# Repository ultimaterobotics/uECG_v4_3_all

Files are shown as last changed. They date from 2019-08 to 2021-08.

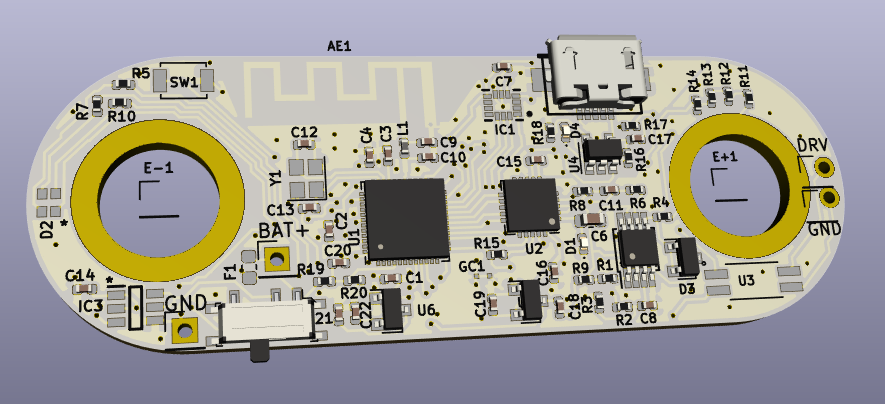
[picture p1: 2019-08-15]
pcb/uECG_rev4_render.png

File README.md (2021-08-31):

# uECG
uECG - very small wearable ECG device that sends raw and processed data over BLE

**This is an old repository - new version is located here: https://github.com/ultimaterobotics/uECG (and is divided into multiple repositories for relevant parts of the project, links are in description)**

Project is in active development stage, at the current moment we have shared:
 * schematics and PCB design
 * ECG monitor program based on Node.js, cross-platform
 * ECG monitor program for Linux (outdated: might not work properly, please use cross-platform version instead)
 * Firmware for the main unit, rather stable and reliable build. Next planned major update will cover better beat detection and more robust bpm processing. 
 * Firmware for the base unit that supports uploading uECG firmware via radio
 * Android app with major rework, quite stable now
 * bootloader code for USB base station: supports base firmware update via USB without the need of STLink programmer
 * bootloader code for uECG device: supports firmware update via radio (requires base with new firmware, old base firmware doesn't support this function)

You can follow the project on Hackaday: https://hackaday.io/project/164486-uecg-a-very-small-wearable-ecg

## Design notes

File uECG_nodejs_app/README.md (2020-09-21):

## uECG PC monitor - browser version, based on node.js

This app at the moment basically duplicates functionality of Android app, but works with x8 higher data rate. In the near future we plan to add support of multiple devices and reduce amount of lost data, then focus on data analysis

## Usage

1. Install Node JS (with npm). The process is quite intuitive and there are plenty of tutorials on how to make it
2. Download the app (git clone, or simply download all files from this folder in a convenient place)
3. Go to the app folder via command line. For this:
  - on Linux and macOS: start the terminal, run series of `cd <folder_name>` commands to get to the folder with downloaded app (where "server.js" file is located)
 - on Windows: start cmd app for accessing command line, if the app folder is not on disk C - run `D:` if it's on D, `E:` if it's on E etc, then run series of `cd <folder_name>` commands to get to the folder with downloaded app (where "server.js" file is located)
4. Install two required packages by running commands:
```
npm install express
npm install serialport
```
5. On Windows and macOS, install drivers for cp2102 chips from here: https://www.silabs.com/products/development-tools/software/usb-to-uart-bridge-vcp-drivers (not needed on Linux)
6. Start the server via command line interface: while in the app folder, run `node server.js`
7. In browser, enter address 127.0.0.1:8080 to access the UI. Note: if you already have some web development environment running on the port 8080, node server won't override it - in this case you can change the port number in the last line of server.js to any other value (and use it in browser correspondingly)
8. On uECG device, after it's turned on and finished blinking startup sequence, press button once to switch it into direct stream mode - after that, you should immediately see data in the browser interface. (pressing the button 2nd time would switch it in arduino-compatible streaming mode, also recognized by the base station, and pressing it for the 3rd time returns to BLE mode, the base won't receive this signal)

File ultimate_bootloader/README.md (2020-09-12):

Base unit bootloader. Supports uploading code via USB - so once it's uploaded via STLink, further updates can be performed more easily. Runs code located at address 0x4000 - so requires firmware to be built with  FLASH (rx) : ORIGIN = 0x04000 in .ld file.

Bootloader waits for firmware update request for 2.5 seconds, then starts the code. Can't auto-reset the base on request (like Arduino) due to missing connection on the base station PCB - base was designed long before bootloader appeared in our plans :)

# bootloader notes

Creating a bootloader for nRF52x chips was our goal for a long while, yet for a long time it didn't work. Somehow we couldn't find any clear instructions how to make it - and it has 3 points of failure, so it's really complicated to make it by trial-and-error.
Eventually it did work though, so I will outline those points:

1. jump to the right address. Jump code must be handled by assembly, and jump itself is a simple BX command, a 5-lines ASM function can conveniently wrap all that's needed in this regard (in our implementation you can find it under the name start_code2(uint32_t start_addr)). But! If you assume that if program starts at 0x4000 then jump should be performed to 0x4000 - you are wrong! After compiling binary code, program's start point is storen in 2nd 32-bit word from the start. So bytes 4-7 of the .bin file define address where jump should be performed.

2. before making the jump, all interrupts must be disabled and VTOR register updated - without this, interrupts won't work. Our current level of understanding isn't good enough to properly explain details, basically VTOR tells where to look for interrup handling functions, and by default it points at bootloader's interrupts. After this interrupts should be enabled again (but not called) - so the program that would be launched has access to them. This piece is handled in our code by function binary_exec(uint32_t address)

3. target app must be compiled with proper origin address. First bytes of the flash memory are occupied by bootloader, so target app should start at higher address - and all function calls should know that it's not starting at zero. To do this, in .ld file an offset must be specified:   FLASH (rx) : ORIGIN = 0x04000 (if bootloader writes program code starting at 0x4000 and uses bytes 0x4004-0x4007 to determine jump point for starting the program.

Keeping these 3 points in mind you should be able to write your own bootloader without any trouble :)

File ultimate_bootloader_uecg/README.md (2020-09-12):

uECG device bootloader code with radio uploading capability.

Bootloader waits for 1.5 seconds after powering on uECG - if button is pressed within this time, it enters wireless update mode for 15 seconds (if code update wasn't started in this time frame, update is cancelled and unit proceeds to normal boot).

Wireless update requires base station with this capability (old base firmware doesn't support it). Update is safe in the sense that it can't overwrite the bootloader: if for any reason attemp wasn't successful, it can be repeated as many times as needed.

Bootloader runs code located at address 0x4000 so firmware should be built with FLASH (rx) : ORIGIN = 0x04000 in .ld file (bootloader ignores attempts to write at addresses below 0x4000).

## bootloader notes

General part (a copy of notes from USB bootloader):

Creating a bootloader for nRF52x chips was our goal for a long while, yet for a long time it didn't work. Somehow we couldn't find any clear instructions how to make it - and it has 3 points of failure, so it's really complicated to make it by trial-and-error. Eventually it did work though, so I will outline those points:

jump to the right address. Jump code must be handled by assembly, and jump itself is a simple BX command, a 5-lines ASM function can conveniently wrap all that's needed in this regard (in our implementation you can find it under the name start_code2(uint32_t start_addr)). But! If you assume that if program starts at 0x4000 then jump should be performed to 0x4000 - you are wrong! After compiling binary code, program's start point is storen in 2nd 32-bit word from the start. So bytes 4-7 of the .bin file define address where jump should be performed.

before making the jump, all interrupts must be disabled and VTOR register updated - without this, interrupts won't work. Our current level of understanding isn't good enough to properly explain details, basically VTOR tells where to look for interrup handling functions, and by default it points at bootloader's interrupts. After this interrupts should be enabled again (but not called) - so the program that would be launched has access to them. This piece is handled in our code by function binary_exec(uint32_t address)

target app must be compiled with proper origin address. First bytes of the flash memory are occupied by bootloader, so target app should start at higher address - and all function calls should know that it's not starting at zero. To do this, in .ld file an offset must be specified: FLASH (rx) : ORIGIN = 0x04000 (if bootloader writes program code starting at 0x4000 and uses bytes 0x4004-0x4007 to determine jump point for starting the program.

Keeping these 3 points in mind you should be able to write your own bootloader without any trouble :)

### Radio specific part:

Radio packets arrive corrupted or completely missing way too often to write them directly on flash. In our implementation each packet has 3 checksums (total, odd, every 3rd byte) and sends confirmation after every packet (if base didn't receive confirmation, it re-sends packet, so we also need to handle duplicate packets). But when all of it is done properly, the process seems to be quite reliable - it passed all tests with moving unit out of range, keeping it at max range (so less than half packets can get through), cutting power in the middle - so it looks ok for now, even though a bit slow (unnecessarily slow, but rewriting it requires time we need to move other parts of the project - will do that later, as always :) )

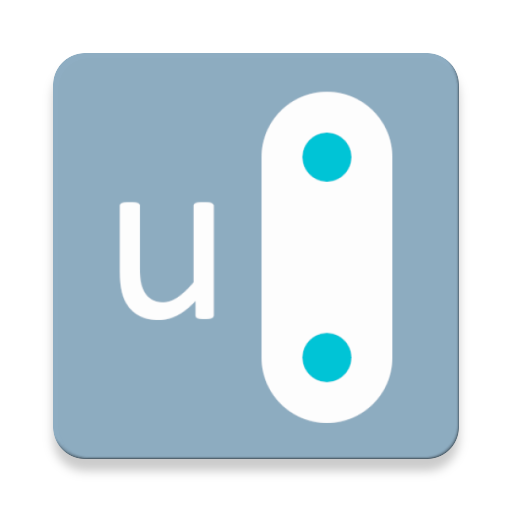
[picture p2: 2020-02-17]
uECG_v4_2_monitor/uECG_v4_2/src/main/ic_launcher-web.png

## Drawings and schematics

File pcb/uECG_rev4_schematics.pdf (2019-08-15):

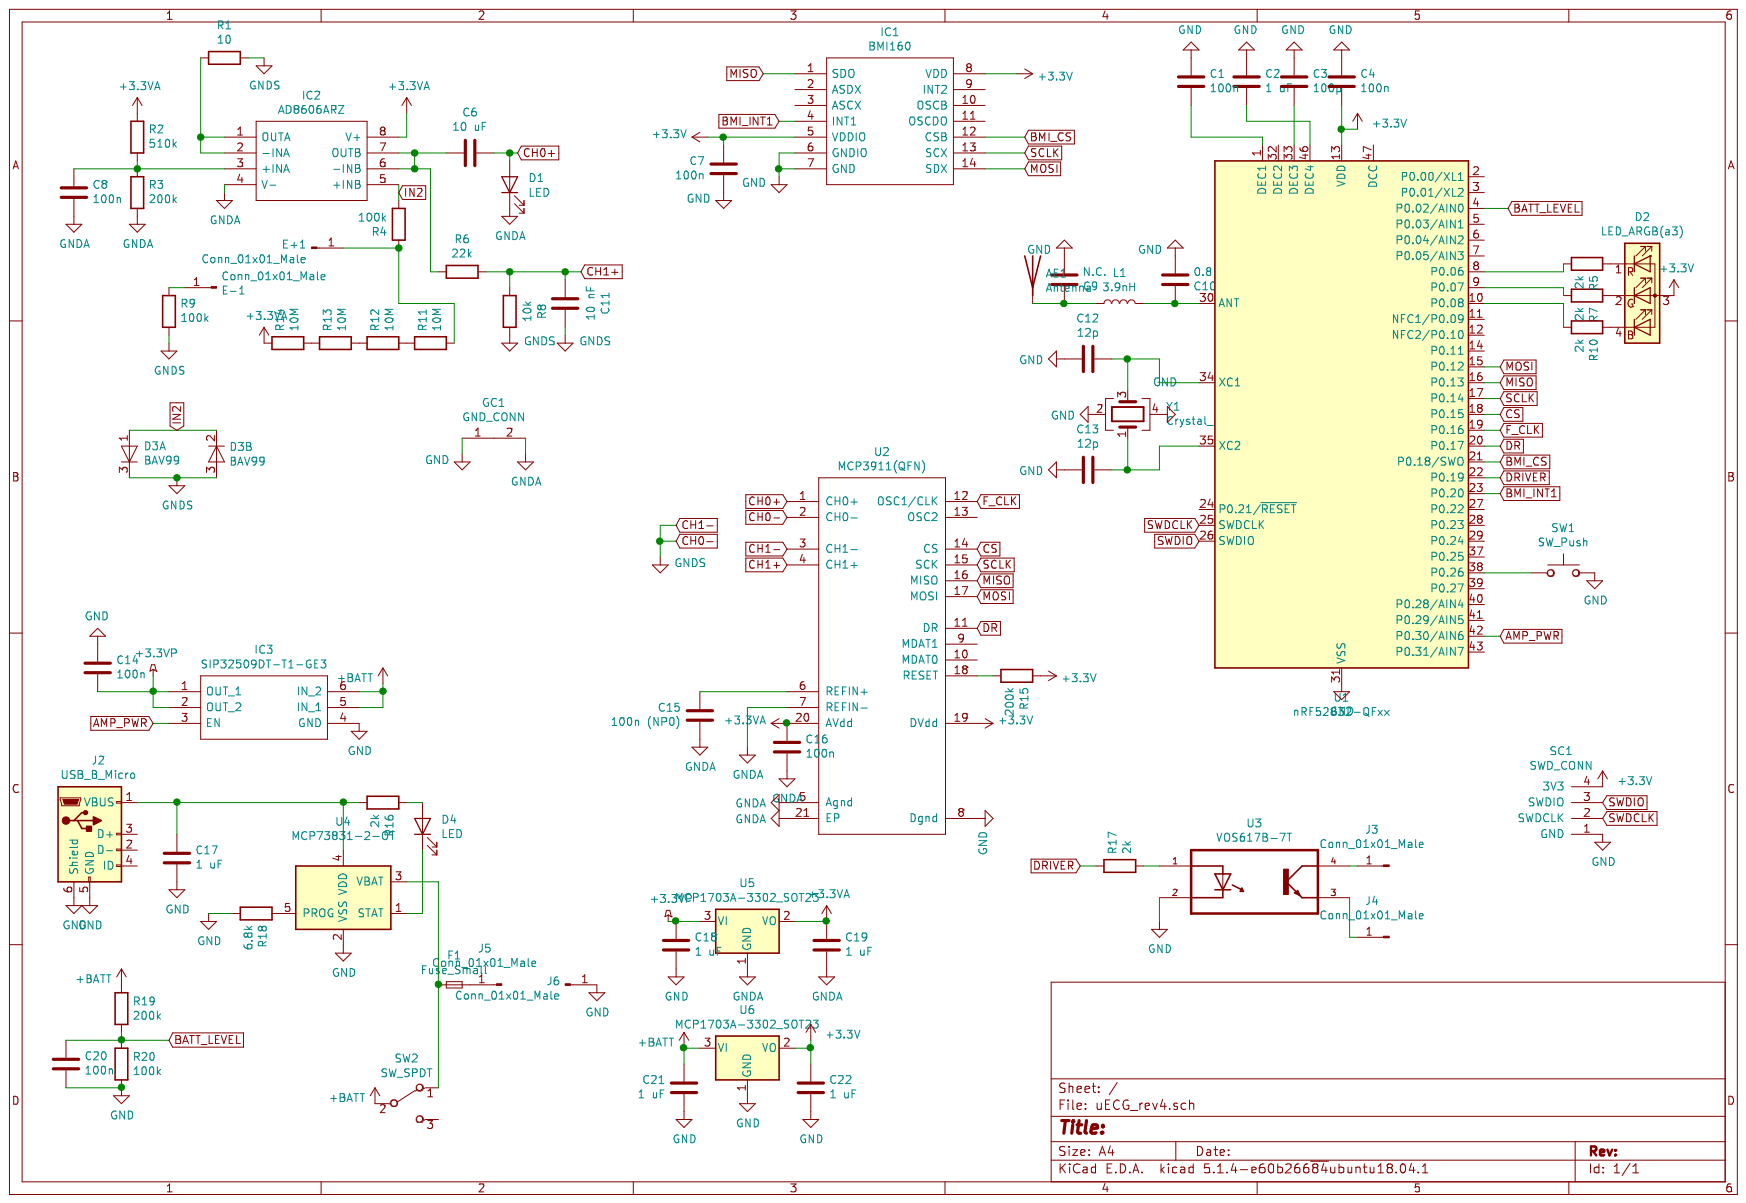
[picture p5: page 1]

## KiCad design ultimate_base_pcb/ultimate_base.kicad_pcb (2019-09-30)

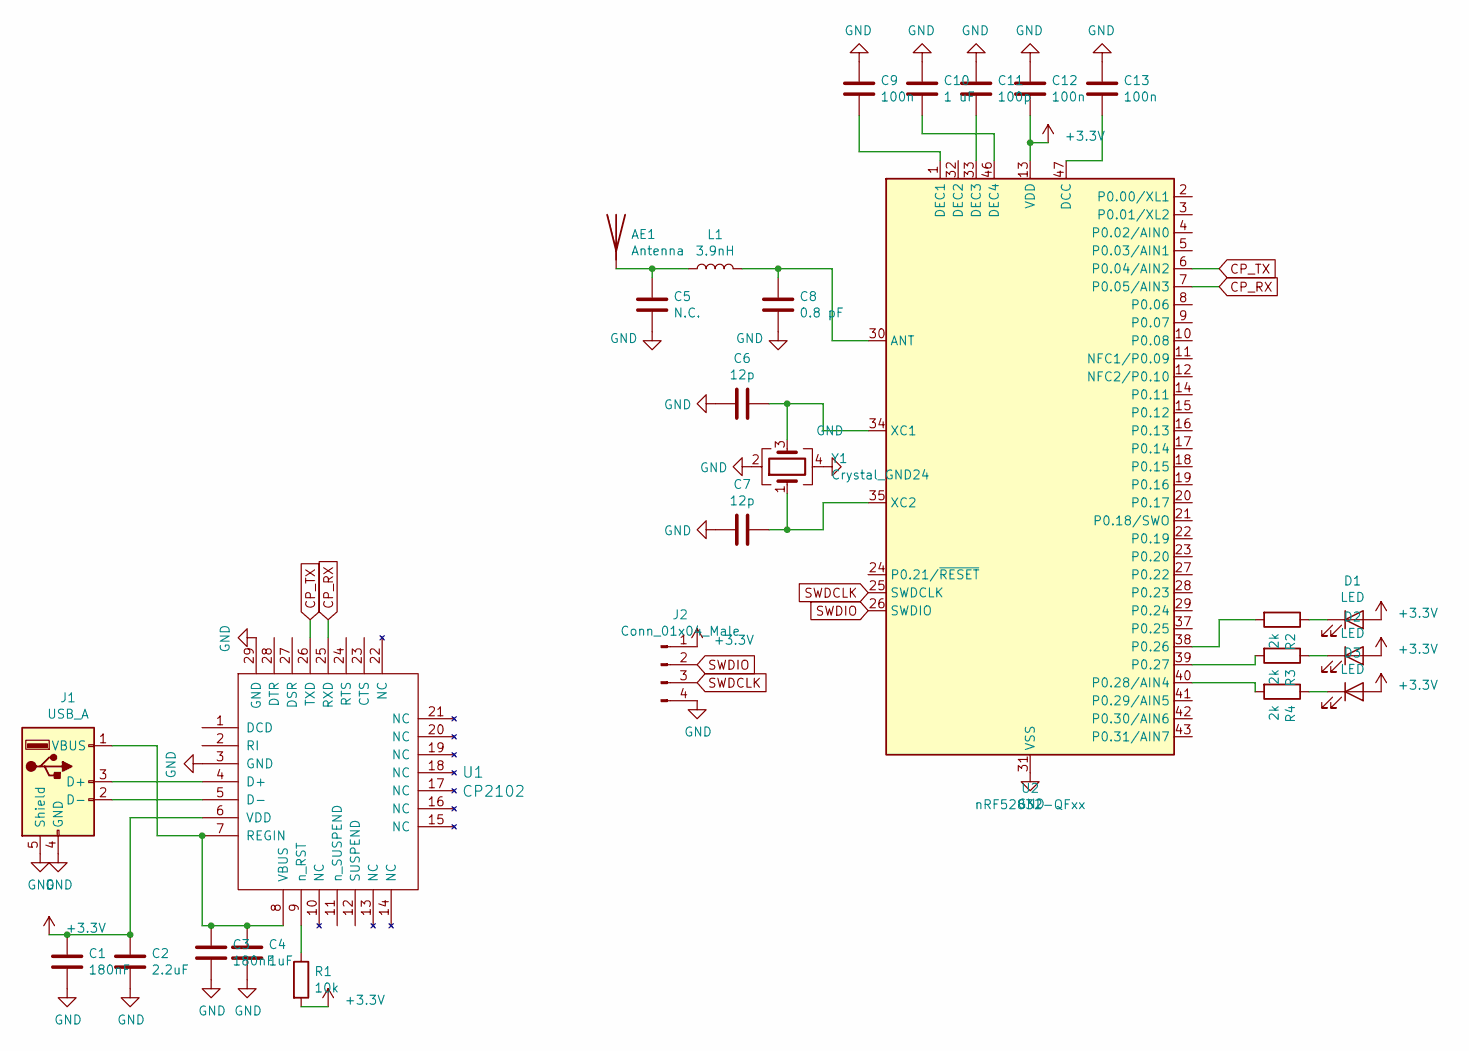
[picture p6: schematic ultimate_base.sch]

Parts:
AE1: Antenna; Texas_SWRA117D_2.4GHz_Left
C1, C3: 180nF; C_0402_1005Metric
C2: 2.2uF; C_0402_1005Metric
C4: 1uF; C_0402_1005Metric
C5: N.C.; C_0402_1005Metric
C6, C7: 12p; C_0402_1005Metric
C8: 0.8 pF; C_0402_1005Metric
C9, C12, C13: 100n; C_0402_1005Metric
C10: 1 uF; C_0402_1005Metric
C11: 100p; C_0402_1005Metric
D1, D2, D3: LED; LED_0603_1608Metric
J1: USB_A; conn_usb_A_china
J2: Conn_01x04_Male; PinHeader_1x04_P2.54mm_Horizontal
L1: 3.9nH; L_0402_1005Metric
R1: 10k; R_0402_1005Metric
R2, R3, R4: 2k; R_0402_1005Metric
U1: CP2102; QFN-28-1EP_5x5mm_P0.5mm_EP3.35x3.35mm
U2: nRF52832-QFxx; QFN-48-1EP_6x6mm_Pitch0.4mm
Y1: Crystal_GND24; Crystal_SMD_2520-4pin_2.5x2.0mm

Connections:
+3V3: C1.1, C2.1, C12.1, D1.2 (A), D2.2 (A), D3.2 (A), J2.1, R1.2, U1.6 (VDD), U2.13 (VDD), U2.36 (VDD), U2.48 (VDD)
CP_RX: U1.25 (RXD), U2.7 (P0.05/AIN3)
CP_TX: U1.26 (TXD), U2.6 (P0.04/AIN2)
GND: AE1.2, C1.2, C2.2, C3.2, C4.2, C5.2, C6.1, C7.1, C8.2, C9.2, C10.2, C11.2, C12.2, C13.2, J1.4 (GND), J1.5 (Shield), J2.4, U1.3 (GND), U1.29 (GND), U2.31 (VSS), U2.45 (VSS), U2.49 (VSS), Y1.2, Y1.4
unnamed: AE1.1, C5.1, L1.1
unnamed: C3.1, C4.1, J1.1 (VBUS), U1.7 (REGIN), U1.8 (VBUS)
unnamed: C6.2, U2.34 (XC1), Y1.3
unnamed: C7.2, U2.35 (XC2), Y1.1
unnamed: C8.1, L1.2, U2.30 (ANT)
unnamed: C9.1, U2.1 (DEC1)
unnamed: C10.1, U2.46 (DEC4)
unnamed: C11.1, U2.33 (DEC3)
unnamed: C13.1, U2.47 (DCC)
unnamed: D1.1 (K), R2.1
unnamed: D2.1 (K), R3.1
unnamed: D3.1 (K), R4.1
unnamed: J1.2 (D-), U1.5 (D-)
unnamed: J1.3 (D+), U1.4 (D+)
unnamed: R1.1, U1.9 (n_RST)
unnamed: R2.2, U2.38 (P0.26)
unnamed: R3.2, U2.39 (P0.27)
unnamed: R4.2, U2.40 (P0.28/AIN4)
SWDCLK: J2.3, U2.25 (SWDCLK)
SWDIO: J2.2, U2.26 (SWDIO)

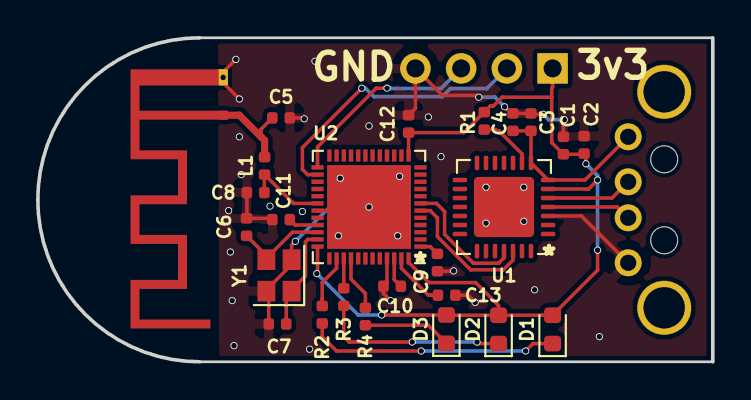
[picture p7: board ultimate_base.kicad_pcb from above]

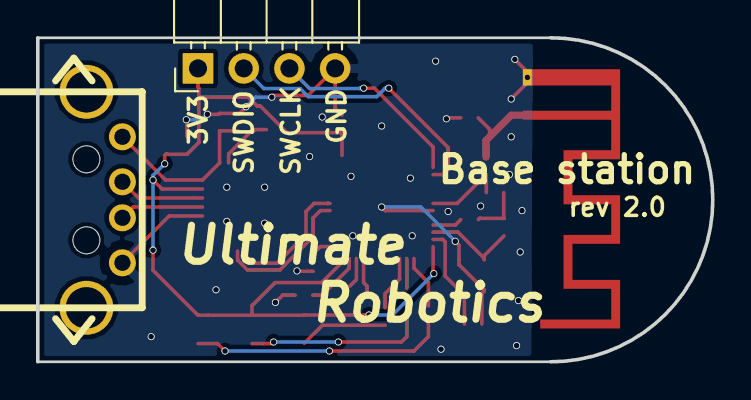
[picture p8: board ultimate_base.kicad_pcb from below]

Board: 2 copper layers, 37.5 x 18.0 mm, 27 parts (2 on the bottom side), 24 nets.

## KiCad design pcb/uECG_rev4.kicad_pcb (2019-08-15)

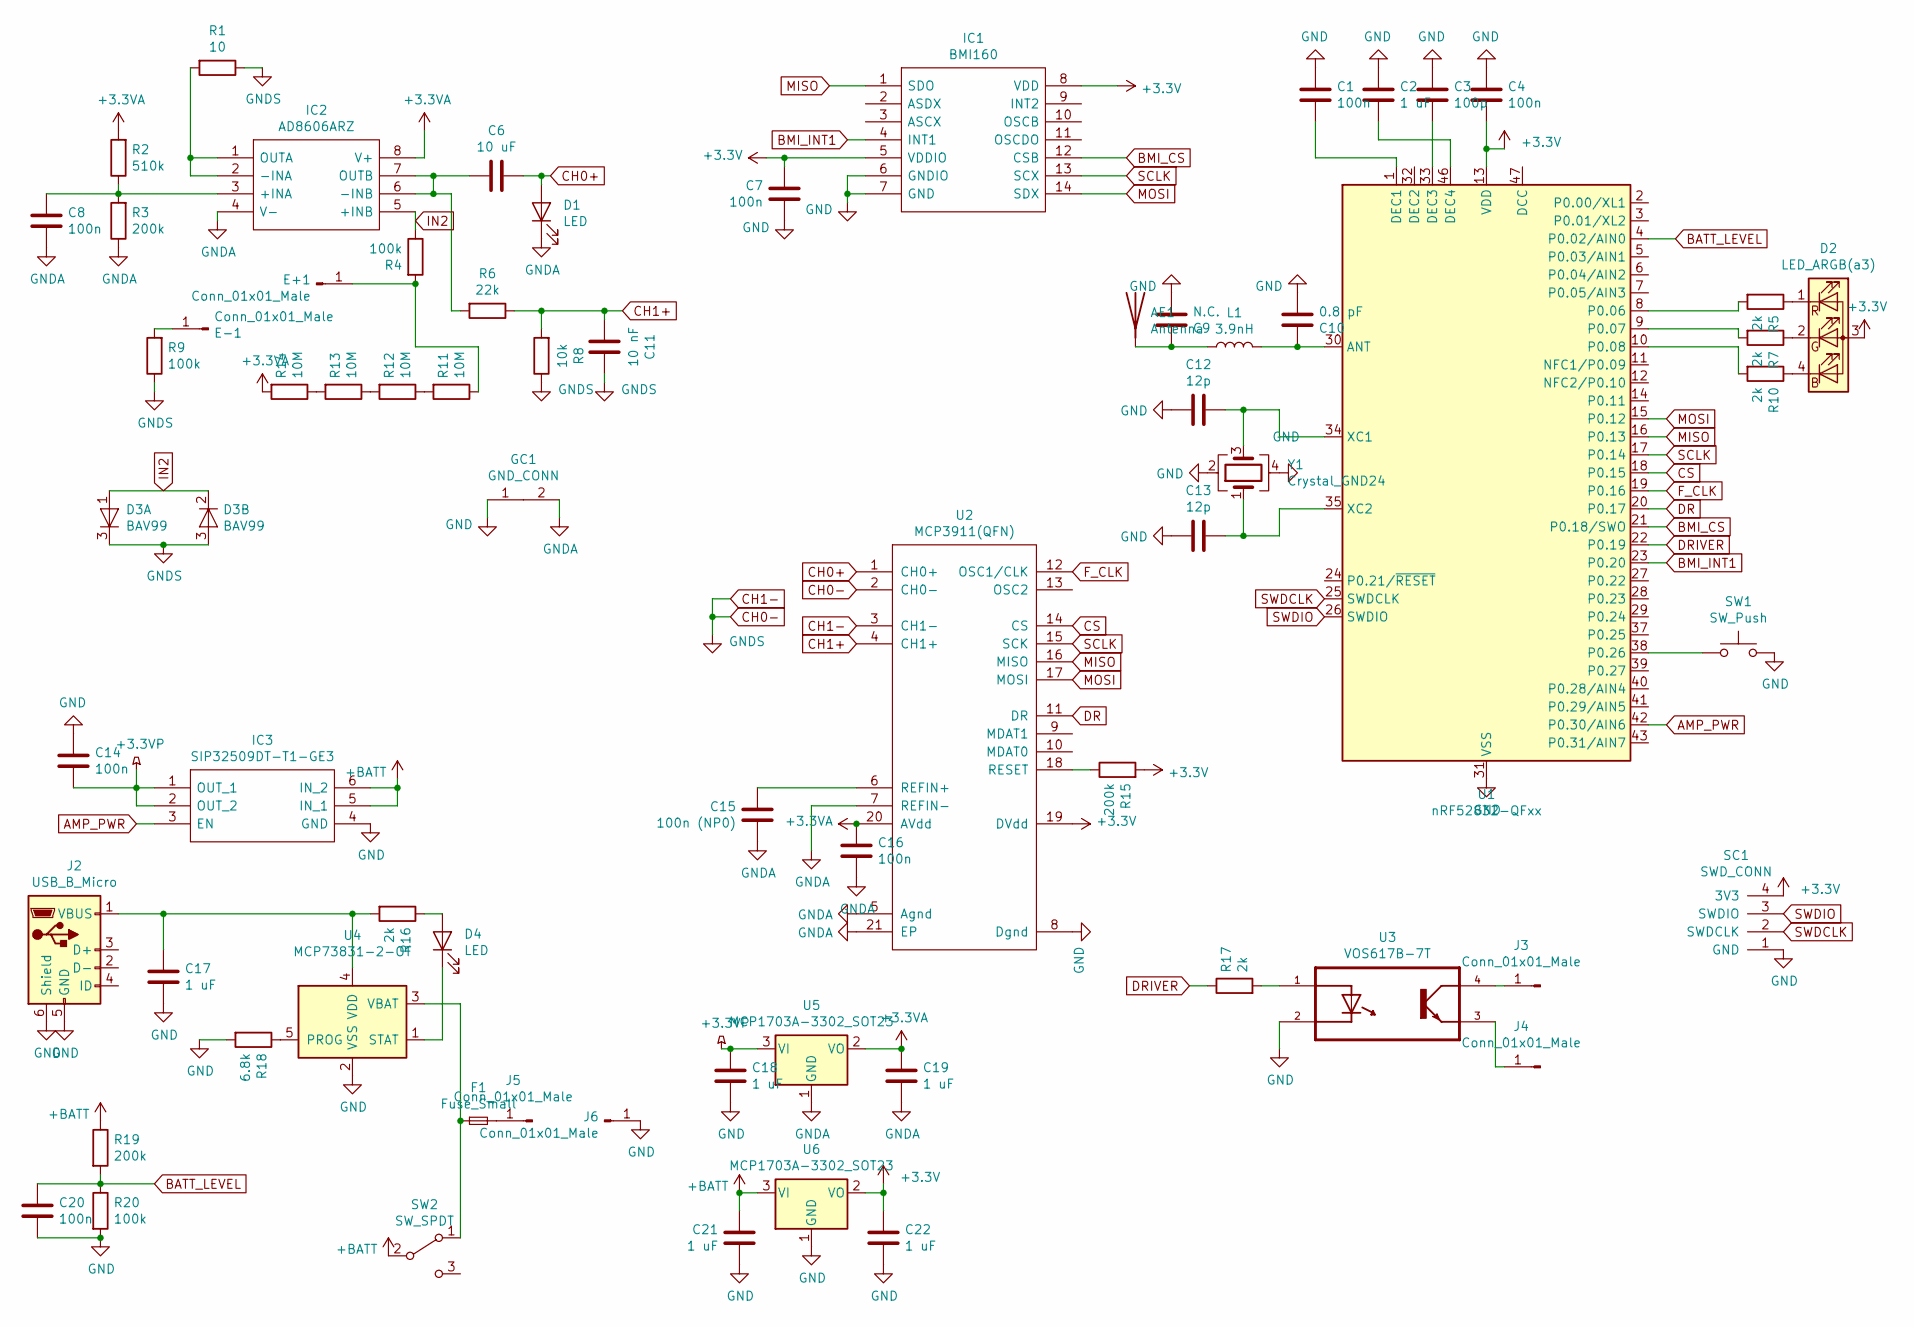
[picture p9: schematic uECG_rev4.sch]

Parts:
AE1: Antenna; Texas_SWRA117D_2.4GHz_Left
C1, C4, C7, C8, C14, C16, C20: 100n; C_0402_1005Metric
C2, C17, C18, C19, C21, C22: 1 uF; C_0402_1005Metric
C3: 100p; C_0402_1005Metric
C6: 10 uF; C_0603_1608Metric
C9: N.C.; C_0402_1005Metric
C10: 0.8 pF; C_0402_1005Metric
C11: 10 nF; C_0402_1005Metric
C12, C13: 12p; C_0402_1005Metric
C15: 100n (NP0); C_0402_1005Metric
D1, D4: LED; LED_0402_1005Metric
D2: LED_ARGB(a3); LED_RGB_0603
D3: BAV99; SOT-23
E+1: Conn_01x01_Male; PinHeader_1x01_P2.54mm_Vertical
E-1: Conn_01x01_Male; PinHeader_1x01_P2.54mm_Vertical
F1: Fuse_Small; Fuse_0603_1608Metric
GC1: GND_CONN
IC1: BMI160; PQFN50P300X250X88-14N; Manufacturer_Part_Number BMI160; Mouser Part Number 262-BMI160
IC2: AD8606ARZ; MSOP-8_3x3mm_P0.65mm; Manufacturer_Part_Number AD8606ARZ; Mouser Part Number 584-AD8606ARZ
IC3: SIP32509DT-T1-GE3; SOT95P284X110-6N; Manufacturer_Part_Number SIP32509DT-T1-GE3
J2: USB_B_Micro; conn_usb_B_micro_smd_our
J3, J5: Conn_01x01_Male; Pin_Header_Straight_1x01_Pitch2.54mm
J4, J6: Conn_01x01_Male; PinHeader_1x01_P2.54mm_Vertical
L1: 3.9nH; L_0402_1005Metric
R1: 10; R_0402_1005Metric
R2: 510k; R_0402_1005Metric
R3, R15, R19: 200k; R_0402_1005Metric
R4, R9, R20: 100k; R_0402_1005Metric
R5, R7, R10, R16, R17: 2k; R_0402_1005Metric
R6: 22k; R_0402_1005Metric
R8: 10k; R_0402_1005Metric
R11, R12, R13, R14: 10М; R_0402_1005Metric
R18: 6.8k; R_0402_1005Metric
SC1: SWD_CONN; SWD_CONNECTOR
SW1: SW_Push; SW_SPST_B3U-1000P
SW2: SW_SPDT; Slider_Switch_ali
U1: nRF52832-QFxx; QFN-48-1EP_6x6mm_Pitch0.4mm
U2: MCP3911(QFN); QFN-20-1EP_4x4mm_P0.5mm_EP2.5x2.5mm
U3: VOS617B-7T; SOIC127P700X210-4N
U4: MCP73831-2-OT; SOT-23-5
U5, U6: MCP1703A-3302_SOT23; SOT-23
Y1: Crystal_GND24; Crystal_SMD_2520-4pin_2.5x2.0mm

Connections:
+3.3VA: C16.2, C19.2, IC2.8 (V+), R2.2, R14.2, U2.20 (AVdd), U5.2 (VO)
+3.3VP: C14.1, C18.2, IC3.1 (OUT_1), IC3.2 (OUT_2), U5.3 (VI)
+3V3: C4.1, C7.2, C22.2, D2.3 (A), IC1.5 (VDDIO), IC1.8 (VDD), R15.2, SC1.4 (3V3), U1.13 (VDD), U1.36 (VDD), U1.48 (VDD), U2.19 (DVdd), U6.2 (VO)
+BATT: C21.2, IC3.5 (IN_1), IC3.6 (IN_2), R19.1, SW2.2 (B), U6.3 (VI)
AMP_PWR: IC3.3 (EN), U1.42 (P0.30/AIN6)
BATT_LEVEL: C20.2, R19.2, R20.1, U1.4 (P0.02/AIN0)
BMI_CS: IC1.12 (CSB), U1.21 (P0.18/SWO)
BMI_INT1: IC1.4 (INT1), U1.23 (P0.20)
CH0+: C6.2, D1.2 (A), U2.1 (CH0+)
CH0-: C11.2, D3.3 (K), R1.1, R8.1, R9.1, U2.2 (CH0-), U2.3 (CH1-)
CH1+: C11.1, R6.1, R8.2, U2.4 (CH1+)
CS: U1.18 (P0.15), U2.14 (CS)
DR: U1.20 (P0.17), U2.11 (DR)
DRIVER: R17.1, U1.22 (P0.19)
F_CLK: U1.19 (P0.16), U2.12 (OSC1/CLK)
GND: AE1.2, C1.2, C2.2, C3.2, C4.2, C7.1, C9.2, C10.2, C12.1, C13.1, C14.2, C17.1, C18.1, C20.1, C21.1, C22.1, GC1.1, IC1.6 (GNDIO), IC1.7 (GND), IC3.4 (GND), J2.5 (GND), J2.6 (Shield), J6.1, R18.2, R20.2, SC1.1 (GND), SW1.2, U1.31 (VSS), U1.45 (VSS), U1.49 (VSS), U2.8 (Dgnd), U3.2 (C), U4.2 (VSS), U6.1 (GND), Y1.2, Y1.4
GNDA: C8.1, C15.1, C16.1, C19.1, D1.1 (K), GC1.2, IC2.4 (V-), R3.1, U2.5 (Agnd), U2.7 (REFIN-), U2.21 (EP), U5.1 (GND)
IN2: D3.1 (A), D3.2 (K), IC2.5 (+INB), R4.1
MISO: IC1.1 (SDO), U1.16 (P0.13), U2.16 (MISO)
MOSI: IC1.14 (SDX), U1.15 (P0.12), U2.17 (MOSI)
unnamed: AE1.1, C9.1, L1.1
unnamed: C1.1, U1.1 (DEC1)
unnamed: C2.1, U1.46 (DEC4)
unnamed: C3.1, U1.33 (DEC3)
unnamed: C6.1, IC2.6 (-INB), IC2.7 (OUTB), R6.2
unnamed: C8.2, IC2.3 (+INA), R2.1, R3.2
unnamed: C10.1, L1.2, U1.30 (ANT)
unnamed: C12.2, U1.34 (XC1), Y1.3
unnamed: C13.2, U1.35 (XC2), Y1.1
unnamed: C15.2, U2.6 (REFIN+)
unnamed: C17.2, J2.1 (VBUS), R16.2, U4.4 (VDD)
unnamed: D2.1 (RK), R5.1
unnamed: D2.2 (GK), R7.1
unnamed: D2.4 (BK), R10.1
unnamed: D4.1 (K), U4.1 (STAT)
unnamed: D4.2 (A), R16.1
unnamed: E+1.1, R4.2, R11.1
unnamed: E-1.1, R9.2
unnamed: F1.1, SW2.1 (A), U4.3 (VBAT)
unnamed: F1.2, J5.1
unnamed: IC2.1 (OUTA), IC2.2 (-INA), R1.2
unnamed: J3.1, U3.4 (CO)
unnamed: J4.1, U3.3 (E)
unnamed: R5.2, U1.8 (P0.06)
unnamed: R7.2, U1.9 (P0.07)
unnamed: R10.2, U1.10 (P0.08)
unnamed: R11.2, R12.1
unnamed: R12.2, R13.1
unnamed: R13.2, R14.1
unnamed: R15.1, U2.18 (RESET)
unnamed: R17.2, U3.1 (A)
unnamed: R18.1, U4.5 (PROG)
unnamed: SW1.1, U1.38 (P0.26)
SCLK: IC1.13 (SCX), U1.17 (P0.14), U2.15 (SCK)
SWDCLK: SC1.2 (SWDCLK), U1.25 (SWDCLK)
SWDIO: SC1.3 (SWDIO), U1.26 (SWDIO)

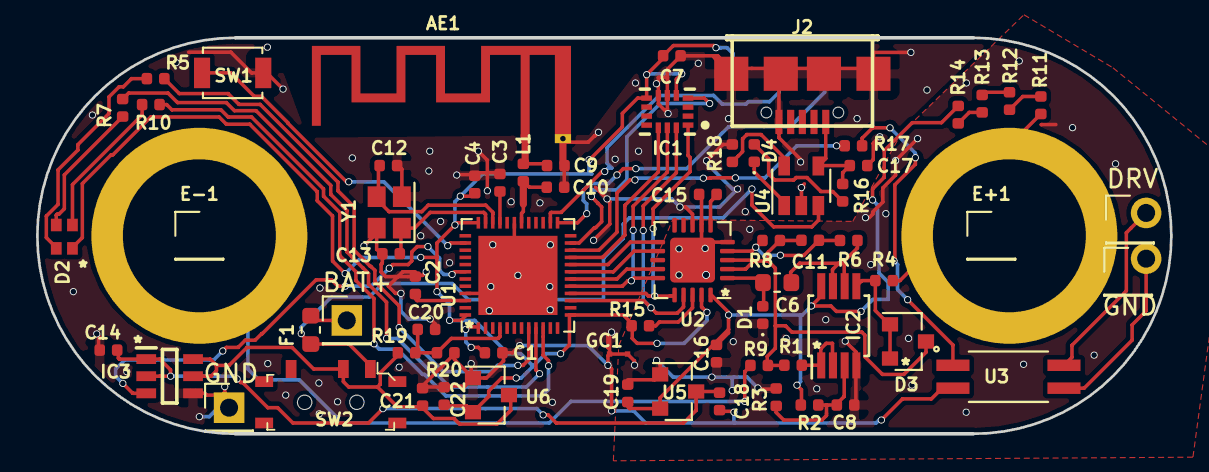
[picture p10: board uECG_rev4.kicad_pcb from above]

Board: 2 copper layers, 63.0 x 22.0 mm, 69 parts (1 on the bottom side), 56 nets.

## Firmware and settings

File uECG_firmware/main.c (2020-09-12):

/**
 */

#include <stdbool.h>
#include <stdint.h>
#include <math.h>
//#include "nrf_delay.h"
//#include "nrf_gpiote.h"
//#include "boards.h"
#include "mcp3911.h"
#include "bmi160.h"
#include "leds.h"
#include "ble_advertising.h"
#include "fast_radio.h"
#include "timer_core.h"

//openocd -f interface/stlink-v2.cfg -f target/nrf52.cfg
//flash write_image erase _build/nrf52832_xxaa.hex

uint8_t pin_button = 26;

float battery_mv = 3500; //by default non zero to prevent power off before actual measurement
int battery_low_threshold = 3200;

uint8_t battery_level = 0;
uint8_t packet_id = 0;
uint8_t adc_working = 0;
uint8_t data_packet[128];

uint8_t enable_led_indication = 1;

int dbg_val = 0;

uint8_t unsent_cnt = 0;
int mcp_buffer[128];
uint8_t mcp_buf_pos = 0;
uint8_t mcp_buf_len = 32;
uint8_t mcp_cnt = 0;

uint32_t spectr_scale = 0;
uint8_t spectr_buf[64];

int mcp_buffer_ble[128];
uint8_t mcp_buf_ble_pos = 0;
uint8_t mcp_buf_ble_len = 32;

int rr_hist_len = 2500;
int rr_hist_pos = 0;
uint16_t RR_hist[2500];

int16_t spectr_val = 0;
uint8_t sp_center_avg = 0;

int out_data_mode = 0;
int emg_mode = 0;

enum
{
	led_out_off = 0,
	led_out_peaks,
	led_out_peaks_inv,
	led_out_analog,
	led_out_analog_inv,
	led_out_maxvalue
};

void rr_init()
{
	for(int x = 0; x < rr_hist_len; x++)
	{
		RR_hist[x] = 0;
	}
}

int BPM = 0;

void update_BPM()
{
	float beats = 20;
	float DT = 0;
	int hpos = rr_hist_pos - 1;
	for(int x = 0; x < beats; x++)
	{
		if(hpos < 0) hpos += rr_hist_len;
		DT += RR_hist[hpos];
		hpos--;
	}
	DT /= 1000.0;
	BPM = 60.0 * beats / DT;
	return;
}

float std_avg = 0.001;
float short_avg = 0.01;
float long_avg = 0.001;
float rr_avg = 0.001;

float avg_RR = 0;

float SDNN = 0;
float RMSSD = 0;
int pNN_bins = 15;
float pNN_short[15];
float pNN_short_norm[15];

void update_HRV()
{
	int hpos = rr_hist_pos - 1;
	if(hpos < 0) hpos += rr_hist_len;
	float rr = RR_hist[hpos];
	hpos--;
	if(hpos < 0) hpos += rr_hist_len;
	float rr2 = RR_hist[hpos];
	
	if(rr < 200 || rr > 2000 || rr2 < 200 || rr2 > 2000) return; //bad RR, no update
	if(avg_RR < 0.0001) avg_RR = rr; //init
	
	avg_RR += rr_avg*rr;
	avg_RR *= 1.0 - rr_avg;

	float aRR = rr - avg_RR;
	SDNN += std_avg*aRR*aRR;
	SDNN *= 1.0 - std_avg;
	
	float dRR = rr - rr2;
	if(dRR < 0) dRR = -dRR;
	float cur_avg_RR = 60.0 / (float)BPM;
	int dRR_bin = dRR / (10.0 * cur_avg_RR);
	if(dRR_bin >= pNN_bins) dRR_bin = pNN_bins-1;

	for(int x = 0; x < pNN_bins; x++)
	{
		pNN_short[x] *= 1.0 - short_avg;
	}
	pNN_short[dRR_bin] += 1.0;

	float sum_short = 0.000001;
	for(int x = 0; x < pNN_bins; x++)
	{
		sum_short += pNN_short[x];
	}
	for(int x = 0; x < pNN_bins; x++)
	{
		pNN_short_norm[x] = pNN_short[x] / sum_short;
	}

	hpos--;
	if(hpos < 0) hpos += rr_hist_len;
	float rr3 = RR_hist[hpos];

	if(rr3 > 200 && rr3 < 2000)
	{
		float ddRR = rr2 - rr3;
		if(ddRR < 0) ddRR = -ddRR;
		float dif_rr = dRR - ddRR;
		RMSSD *= 1.0 - std_avg;
		RMSSD += std_avg*dif_rr*dif_rr;
	}	
}

uint8_t send_rr_id = 0;

void push_RR(uint32_t RR)
{
	RR_hist[rr_hist_pos] = RR;
	rr_hist_pos++;
	if(rr_hist_pos >= rr_hist_len)
		rr_hist_pos = 0;
	
	send_rr_id++;
	if(send_rr_id > 0x0F) send_rr_id = 0;
	
	update_BPM();
	update_HRV();
}


uint8_t led_out_mode = led_out_peaks;
uint8_t emg_data_id = 0;


uint8_t data_id = 0;
uint8_t data_id_ble = 0;
uint8_t param_send_id = 0;

enum param_sends
{
	param_batt_bpm = 0,
	param_sdnn,
	param_skin_res,
	param_lastRR,
	param_imu_acc,
	param_imu_steps,
	param_pnn_bins,
	param_end,
	param_emg_spectrum
};

int send_rr_cnt = 0;
float skin_ble_avg = 0;
int bin_send_id = 0;
float g_activity = 0;

float encode_acc(float acc)
{
	float shift = 0, dA = 0, coeff = 1;
	float am = acc;
	if(am < 0) am = -am;
	if(am < 2)
	{
		shift = 0;
		dA = 0;
		coeff = 25.0;
	}
	else if (am < 12)
	{
		shift = 50;
		dA = 2.0;
		coeff = 5.0;
	}
	else 
	{
		shift = 100;
		dA = 12.0;
		coeff = 2.0;
	}
	float res = shift + (am - dA) * coeff;
	if(acc < 0) res = -res;
	return res;
}

void prepare_data_packet()
{
	uint8_t idx = 0;
	data_packet[idx++] = 0; //fill in the end
	packet_id++;
	if(packet_id > 128) packet_id = 0;
	data_packet[idx++] = packet_id;
	uint32_t unit_id = NRF_FICR->DEVICEID[1];
	data_packet[idx++] = (unit_id>>24)&0xFF;
	data_packet[idx++] = (unit_id>>16)&0xFF;
	data_packet[idx++] = (unit_id>>8)&0xFF;
	data_packet[idx++] = (unit_id)&0xFF;
	uint8_t send_cnt = unsent_cnt;
//	if(send_cnt > 4) send_cnt = 4;
//	if(send_cnt < 1) send_cnt = 1;
	if(emg_mode)
	{
		data_packet[idx++] = 32;
		data_packet[idx++] = battery_level;
		data_packet[idx++] = emg_data_id;
		data_packet[idx++] = sp_center_avg;
		data_packet[idx++] = sp_center_avg;
		if(spectr_scale > 0xFFFF) spectr_scale = 0xFFFF;
		data_packet[idx++] = (spectr_scale>>8)&0xFF;
		data_packet[idx++] = spectr_scale&0xFF;
		for(int n = 0; n < 32; n++)
			data_packet[idx++] = spectr_buf[n];
		data_packet[0] = idx+1;
		uint8_t check = 0;
		for(int x = 0; x < idx; x++)
			check += data_packet[x];
		data_packet[idx] = check;
		return;	
	}
	data_packet[idx++] = send_cnt;
	int cur_send_id;
	param_send_id++;
	if(param_send_id == param_end) param_send_id = 0;
	cur_send_id = param_send_id;

	data_packet[idx++] = cur_send_id;
	if(cur_send_id == param_batt_bpm)
	{
		data_packet[idx++] = battery_level;
		data_packet[idx++] = 5; //version_id
		data_packet[idx++] = BPM;
	}
	if(cur_send_id == param_sdnn)
	{
		int v1 = sqrt(SDNN);
		int v2 = sqrt(RMSSD);
		if(v1 > 0xFFF) v1 = 0xFFF;
		if(v2 > 0xFFF) v2 = 0xFFF;
		uint8_t v1_h = (v1>>8)&0x0F;
		uint8_t v1_l = v1&0xFF;
		uint8_t v2_h = (v2>>8)&0x0F;
		uint8_t v2_l = v2&0xFF;
		data_packet[idx++] = (v1_h<<4) | v2_h;
		data_packet[idx++] = v1_l;
		data_packet[idx++] = v2_l;
	}
	if(cur_send_id == param_skin_res)
	{
		int v = mcp_get_filtered_skin();//skin_ble_avg;
		data_packet[idx++] = v>>8;
		data_packet[idx++] = v&0xFF;
		float temp = bmi.T;
		int ti = temp;
		uint8_t t8 = 0;
		if(ti < -20) ti = -20;
		if(ti > 77) ti = 77;
		if(ti < 30) t8 = 20 + ti;
		if(ti > 47) t8 = 220 + (ti-47);
		if(ti >= 30 && ti <= 47)
		{
			t8 = 50 + (temp-30.0)*10.0;
		}
		data_packet[idx++] = t8;
	}
	if(cur_send_id == param_lastRR)
	{
		int hpos = rr_hist_pos - 1;
		int v1 = RR_hist[hpos];
		uint8_t v1_h = (v1>>8)&0xFF;
		uint8_t v1_l = v1&0xFF;
		data_packet[idx++] = send_rr_id;
		data_packet[idx++] = v1_h;
		data_packet[idx++] = v1_l;
	}
	if(cur_send_id == param_imu_acc)
	{
		int ax = 128 + encode_acc(bmi.aX);
		if(ax < 0) ax = 0;
		if(ax > 255) ax = 255;
		int ay = 128 + encode_acc(bmi.aY);
		if(ay < 0) ay = 0;
		if(ay > 255) ay = 255;
		int az = 128 + encode_acc(bmi.aZ);
		if(az < 0) az = 0;
		if(az > 255) az = 255;
		data_packet[idx++] = ax;
		data_packet[idx++] = ay;
		data_packet[idx++] = az;
	}
	if(cur_send_id == param_imu_steps)
	{
		int steps = bmi.step_cnt;
		int g_byte = g_activity * 10.0;
		if(g_byte > 255) g_byte = 255;
		data_packet[idx++] = (steps>>8)&0xFF;
		data_packet[idx++] = steps&0xFF;
		data_packet[idx++] = g_byte;
	}
	if(cur_send_id == param_pnn_bins)
	{
		int bin_v1 = pNN_short_norm[bin_send_id] * 255.0;
		int bin_v2 = pNN_short_norm[bin_send_id+1] * 255.0;
		data_packet[idx++] = bin_send_id;
		data_packet[idx++] = bin_v1;
		data_packet[idx++] = bin_v2;
		bin_send_id += 2;
		if(bin_send_id >= 15) bin_send_id = 0;
	}
		
	int n = 0;
	int pp = mcp_buf_pos - send_cnt - 1;
	if(pp < 0) pp += mcp_buf_len;
	while(n++ < send_cnt)
	{
		data_packet[idx++] = (mcp_buffer[pp] >> 8)&0xFF;
		data_packet[idx++] = (mcp_buffer[pp]) & 0xFF;
		if(++pp >= mcp_buf_len) pp = 0;
	}

	int16_t v = mcp_get_filtered_skin();//skin_ble_avg;
	data_packet[idx++] = v>>8;
	data_packet[idx++] = v&0xFF;

	data_packet[0] = idx+2;
	uint8_t check = 0;
	for(int x = 0; x < idx; x++)
		check += data_packet[x];
	data_packet[idx++] = check;
	uint8_t check_e = 0;
	for(int x = 0; x < idx; x+=2)
		check_e += data_packet[x];
	data_packet[idx] = check_e;
}

void prepare_data_packet_ble()
{
	data_packet[0] = data_id_ble;
	if(emg_mode)
	{
		data_packet[1] = param_emg_spectrum;
		data_packet[2] = battery_level;
		data_packet[3] = emg_data_id;
		data_packet[4] = sp_center_avg;
		if(spectr_scale > 0xFFFF) spectr_scale = 0xFFFF;
		data_packet[5] = (spectr_scale>>8)&0xFF;
		data_packet[6] = spectr_scale&0xFF;
		//14 bytes left, so pack them carefully
		int idx = 7;
		for(int n = 1; n < 5; n++) //first 4 directly
			data_packet[idx++] = spectr_buf[n];
		//10 bytes left, packing sp[5]...sp[14]
		for(int n = 0; n < 5; n++)
			data_packet[idx++] = (spectr_buf[5+n*2] + spectr_buf[5+n*2+1])/2;
		//5 bytes left, packing sp[15]...sp[29]
		for(int n = 0; n < 5; n++)
			data_packet[idx++] = (spectr_buf[15+n*3] + spectr_buf[15+n*3+1] + spectr_buf[15+n*3+2])/3;
		return;
	}
	int skin_res = mcp_get_filtered_skin();
	skin_ble_avg *= 0.98;
	skin_ble_avg += 0.02*skin_res;
	int cur_send_id;
	param_send_id++;
	if(param_send_id == param_end) param_send_id = 0;
	cur_send_id = param_send_id;

	data_packet[1] = cur_send_id;
	if(cur_send_id == param_batt_bpm)
	{
		data_packet[2] = battery_level;
		data_packet[3] = 5; //version_id
		data_packet[4] = BPM;
	}
	if(cur_send_id == param_sdnn)
	{
		int v1 = sqrt(SDNN);
		int v2 = sqrt(RMSSD);
		if(v1 > 0xFFF) v1 = 0xFFF;
		if(v2 > 0xFFF) v2 = 0xFFF;
		uint8_t v1_h = (v1>>8)&0x0F;
		uint8_t v1_l = v1&0xFF;
		uint8_t v2_h = (v2>>8)&0x0F;
		uint8_t v2_l = v2&0xFF;
		data_packet[2] = (v1_h<<4) | v2_h;
		data_packet[3] = v1_l;
		data_packet[4] = v2_l;
	}
	if(cur_send_id == param_skin_res)
	{
		int v = skin_ble_avg;
		data_packet[2] = v>>8;
		data_packet[3] = v&0xFF;
		float temp = bmi.T;
		int ti = temp;
		uint8_t t8 = 0;
		if(ti < -20) ti = -20;
		if(ti > 77) ti = 77;
		if(ti < 30) t8 = 20 + ti;
		if(ti > 47) t8 = 220 + (ti-47);
		if(ti >= 30 && ti <= 47)
		{
			t8 = 50 + (temp-30.0)*10.0;
		}
		data_packet[4] = t8;
	}
	if(cur_send_id == param_lastRR)
	{
		int hpos = rr_hist_pos - 1;
		if(hpos < 0) hpos += rr_hist_len;
		int hpos2 = hpos - 1;
		if(hpos2 < 0) hpos2 += rr_hist_len;
		int v1 = RR_hist[hpos];
		int v2 = RR_hist[hpos2];
		if(v1 > 0xFFF) v1 = 0xFFF;
		if(v2 > 0xFFF) v2 = 0xFFF;
		uint8_t v1_h = (v1>>8)&0x0F;
		uint8_t v1_l = v1&0xFF;
		uint8_t v2_h = (v2>>8)&0x0F;
		uint8_t v2_l = v2&0xFF;
		data_packet[1] |= send_rr_id<<4;
		data_packet[2] = (v1_h<<4) | v2_h;
		data_packet[3] = v1_l;
		data_packet[4] = v2_l;
	}
	if(cur_send_id == param_imu_acc)
	{
		int ax = 128 + encode_acc(bmi.aX);
		if(ax < 0) ax = 0;
		if(ax > 255) ax = 255;
		int ay = 128 + encode_acc(bmi.aY);
		if(ay < 0) ay = 0;
		if(ay > 255) ay = 255;
		int az = 128 + encode_acc(bmi.aZ);
		if(az < 0) az = 0;
		if(az > 255) az = 255;
		data_packet[2] = ax;
		data_packet[3] = ay;
		data_packet[4] = az;
	}
	if(cur_send_id == param_imu_steps)
	{
		int steps = bmi.step_cnt;
		int g_byte = g_activity * 10.0;
		if(g_byte > 255) g_byte = 255;
		data_packet[2] = (steps>>8)&0xFF;
		data_packet[3] = steps&0xFF;
		data_packet[4] = g_byte;
	}

	if(cur_send_id == param_pnn_bins)
	{
		int bin_v1 = pNN_short_norm[bin_send_id] * 255.0;
		int bin_v2 = pNN_short_norm[bin_send_id+1] * 255.0;
		int bin_v3 = pNN_short_norm[bin_send_id+2] * 255.0;
		data_packet[1] |= (bin_send_id<<4);
		bin_send_id += 3;
		if(bin_send_id >= 13) bin_send_id = 0;
		data_packet[2] = bin_v1;
		data_packet[3] = bin_v2;
		data_packet[4] = bin_v3;
	}
	int send_seq_cnt = 30; //definitely enough for any BLE4 case
	int pp = mcp_buf_ble_pos - send_seq_cnt - 1;
	if(pp < 0) pp += mcp_buf_ble_len;
	uint8_t idx = 5;
	int zero_val = mcp_buffer_ble[pp];
	data_packet[idx++] = (zero_val >> 8)&0xFF;
	data_packet[idx++] = (zero_val) & 0xFF;
	int start_pp = pp;
	int prev_vv = zero_val;
	int cur_scale = 1;
	int max_dv = 0;
	for(int x = 0; x < send_seq_cnt; x++)
	{
		if(++pp >= mcp_buf_ble_len) pp = 0;
		int vv = mcp_buffer_ble[pp];
		int dv = vv - prev_vv;
		if(dv < 0) dv = -dv;
		if(dv > max_dv) max_dv = dv;
		prev_vv = vv;
	}
	cur_scale = 1 + (max_dv / 127);
	int scale_code = cur_scale;
	if(scale_code > 100) scale_code = 100 + (scale_code-100) / 4;
	data_packet[idx++] = scale_code;
	pp = start_pp;
	prev_vv = zero_val;
	for(int x = 0; x < send_seq_cnt; x++)
	{
		if(++pp >= mcp_buf_ble_len) pp = 0;
		int vv = mcp_buffer_ble[pp];
		int dv = (vv - prev_vv) / cur_scale;
		data_packet[idx++] = dv&0xFF;
		prev_vv = vv;
	}
}

float avg_v = 0;
float avg_dv = 0;
float avg_dv_f = 0;

int prev_v = 0;
float prev_peak = 0;
int prev_peak_cnt = 0;

float avg_base = 0;
float avg_local = 0;
float avg_max = 0;
float avg_min = 0;
float loc_max = 0;
float loc_min = 0;

int peak_in = 0;

uint32_t peak_start_ms = 0;
uint32_t prev_peak_start = 0;

int val_ble = 0;
int val_ble_z = 0;

void h2color(int h, uint8_t *r, uint8_t *g, uint8_t *b) //HSV color model with S=V=100
{
	uint8_t hi = (h/60)%6;
	uint8_t a = (h%60)*51/12; //a: 0...255
	uint8_t Vinc = a;
	uint8_t Vdec = 255 - a;

	switch(hi)
	{
		case 0: 
			*r = 255;
			*g = Vinc;
			*b = 0;
			break;
		case 1: 
			*r = Vdec;
			*g = 255;
			*b = 0;
			break;
		case 2: 
			*r = 0;
			*g = 255;
			*b = Vinc;
			break;
		case 3: 
			*r = 0;
			*g = Vdec;
			*b = 255;
			break;
		case 4: 
			*r = Vinc;
			*g = 0;
			*b = 255;
			break;
		case 5: 
			*r = 255;
			*g = 0;
			*b = Vdec;
			break;
		default:
			*r = 255;
			*g = 255;
			*b = 255;
	}
	return;
}

int emu_data = 0;
int emu_cnt = 0;
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
int main(void)
{
	int init_ok = 1;
	
	NRF_UICR->NFCPINS = 0;

	NRF_GPIO->PIN_CNF[pin_button] = (0b11 << 2); // pull up << 2 | input buffer << 1 | dir << 0
//	NRF_GPIO->DIRCLR = 1<<pin_button;

	fast_clock_start();
	start_time();
	NRF_GPIO->DIRSET = 1<<11;
	NRF_GPIO->OUTSET = 1<<11;
	leds_init();

//	NRF_POWER->DCDCEN = 1;

	for(int x = 0; x < 3; x++)
	{
		leds_set((x==0)*255, (x==1)*255, (x==2)*255);
		delay_ms(300);
	}
//	leds_set_driver(55);
//	leds_set(255, 60, 120);
	leds_set(0, 0, 0);
	delay_ms(300);

	if(radio_mode == radio_mode_ble)
		config_ble_adv();
	if(radio_mode == radio_mode_fast)
	{
		fr_init(32);
		fr_listen();
	}
	if(radio_mode == radio_mode_fast64)
	{
		fr_init(64);
		fr_listen();
	}
	
	init_mcp3911(13, 12, 14, 15, 17);
	if(!mcp3911_is_ok())
	{
		init_ok = 0;
		leds_set(255, 0, 0);
		delay_ms(1000);
		leds_set(0, 0, 0);
		delay_ms(200);
		leds_set(255, 0, 255);
		delay_ms(1000);
		leds_set(0, 0, 0);
		delay_ms(200);
	}
	bmi160_init(13, 12, 14, 18, 20);
	if(!bmi160_is_ok())
	{
		init_ok = 0;
		leds_set(255, 0, 0);
		delay_ms(1000);
		leds_set(0, 0, 0);
		delay_ms(200);
		leds_set(255, 255, 0);
		delay_ms(1000);
		leds_set(0, 0, 0);
		delay_ms(200);
	}
	if(!(NRF_GPIO->IN & 1<<pin_button))
	{
		leds_set(255, 0, 0);
		delay_ms(1000);
		leds_set(0, 0, 0);
		delay_ms(200);
		leds_set(0, 0, 255);
		delay_ms(1000);
		leds_set(0, 0, 0);
		delay_ms(200);
	}
	

//	leds_set(0, 255, 0);

	delay_ms(100);
	
	rr_init();

	uint32_t last_sent_ms = 0;
	uint8_t ble_send_cnt = 0;
	uint8_t btn_pressed = 0;
	uint32_t btn_on = 0;
	uint32_t btn_off = 0;
	
	int measure_skin = 0;
	uint32_t last_skin_time = 0;
	measure_skin = 1;
	
	NRF_RNG->TASKS_START = 1;
	NRF_RNG->SHORTS = 0;
	NRF_RNG->CONFIG = 1;
	
	int ble_dt1 = 5;
	int ble_dt2 = 5;
	int send_iter = 0;
	int low_bat_cnt = 0;
	
	int bmi_skip_cnt = 0;
	
	if(init_ok)
	{
		for(int x = 0; x < 3; x++)
		{
			leds_set(0, 255, 0);
			delay_ms(200);
			leds_set(0, 0, 0);
			delay_ms(200);
		}
	}

	while(1)
	{
//		low_power_cycle();
		uint32_t ms = millis();
		if(0)if(measure_skin == 0 && ms - last_skin_time > 5000)
		{
			measure_skin = 1;
			last_skin_time = ms;
		}
		if(0)if(measure_skin == 1 && ms - last_skin_time > 5)
		{
			measure_skin = 0;
			last_skin_time = ms;
		}
		
		if(!(NRF_GPIO->IN & 1<<pin_button))
		{
			enable_led_indication = 0;
			if(!btn_pressed)
			{
				btn_pressed = 1;
				btn_on = ms;
			}
			if(ms - btn_on > 25 && ms - btn_on < 1000)
				leds_set(0, 0, 255);
			if(ms - btn_on > 1000 && ms - btn_on < 5000)
				leds_set(0, 255, 0);
			if(ms - btn_on > 5000)
				leds_set(255, 255, 255);
		}
		else
		{
			enable_led_indication = 1;
			if(btn_pressed)
			{
				btn_pressed = 0;
				btn_off = ms;
				uint32_t btn_time = btn_off - btn_on;
				if(btn_time > 25) //ignore too short presses - noise
				{
					if(btn_time < 1000)
						process_btn_short();
					else if(btn_time < 5000)
						process_btn_long();
				}
//				mcp_set_filter_mode(radio_mode == radio_mode_ble);
			}
		}
		if(mcp3911_read())
		{
			if(push_mcp_data())
			{
				mcp_cnt++;
				data_id++;
	//			if(mcp_cnt > 128)
	//				leds_set(255, 255, 1);
	//			else
	//				leds_set(255, 255, 0);
				
				if(unsent_cnt < 30) unsent_cnt++;
				read_battery();
				if(battery_mv < battery_low_threshold)
				{
					low_bat_cnt++;
					if(low_bat_cnt > 100)
						mode_lowbatt();
				}
				else
					low_bat_cnt = 0;
			}
			if(!emg_mode)
			{
				bmi160_read();
				bmi_skip_cnt++;
				if(bmi_skip_cnt == 10)
				{
					bmi160_read_temp();
				}
				if(bmi_skip_cnt > 20)
				{
					bmi160_read_steps();
					bmi_skip_cnt = 0;
				}
			}
/*			if(0)if(fft_pending())
			{
				fft_skip_cnt++; 
				if(fft_skip_cnt > 0)
				{
//					sfft_butterfly();
					int cv = 10 + get_avg_sp();
					//if(cv > spectr_val && cv < 400) 
						spectr_val = cv;
					fft_skip_cnt = 0;
				}
			}*/
			
		}		

		if(radio_mode == radio_mode_fast)
		{
			if(unsent_cnt > 5*(!emg_mode) && ms - last_sent_ms > ble_dt1)
			{
				prepare_data_packet();
				fr_send_and_listen(data_packet);
				unsent_cnt = 0;
				last_sent_ms = ms;
				send_iter = 1;
				if(NRF_RNG->EVENTS_VALRDY)
				{
					volatile int rnd = NRF_RNG->VALUE;
					NRF_RNG->EVENTS_VALRDY = 0;
					ble_dt1 = 1 + 2*emg_mode + (rnd >> 6);
					ble_dt2 = 1 + 2*emg_mode + (rnd%(3+3*emg_mode));
					NRF_RNG->TASKS_START;
				}
			}
			
			if(last_sent_ms > 0 && ms - last_sent_ms > ble_dt2 && send_iter == 1)
			{
				fr_send_and_listen(data_packet);
				send_iter = 2;
			}
			if(last_sent_ms > 0 && ms - last_sent_ms > 2*ble_dt2 && send_iter == 2)
			{
				fr_send_and_listen(data_packet);
				send_iter = 3;
			}
			if(last_sent_ms > 0 && ms - last_sent_ms > 3*ble_dt2 && send_iter == 3)
			{
				fr_send_and_listen(data_packet);
				send_iter = 4;
			}
		}

		if(radio_mode == radio_mode_fast64)
		{
			if(unsent_cnt > 15*(!emg_mode) && ms - last_sent_ms > ble_dt1)
			{
				prepare_data_packet();
				fr_send_and_listen(data_packet);
				unsent_cnt = 0;
				last_sent_ms = ms;
				send_iter = 1;
				if(NRF_RNG->EVENTS_VALRDY)
				{
					volatile int rnd = NRF_RNG->VALUE;
					NRF_RNG->EVENTS_VALRDY = 0;
					ble_dt1 = 1 + 2*emg_mode + (rnd >> 6);
					ble_dt2 = 1 + 2*emg_mode + (rnd%(3+3*emg_mode));
					NRF_RNG->TASKS_START;
				}
			}
			
			if(last_sent_ms > 0 && ms - last_sent_ms > ble_dt2 && send_iter < 5)
			{
				fr_send_and_listen(data_packet);
				last_sent_ms = ms;
				send_iter++;
			}
		}
		
		if(radio_mode == radio_mode_ble)
		{
			int dt = ble_dt1, dt2 = ble_dt2;
			if(ms - last_sent_ms > dt)
			{
				prepare_data_packet_ble();
				prepare_adv_packet(data_packet, 40);
				send_adv_packet();
				ble_send_cnt = 1;
				last_sent_ms = ms;

				if(NRF_RNG->EVENTS_VALRDY)
				{
					volatile int rnd = NRF_RNG->VALUE;
					NRF_RNG->EVENTS_VALRDY = 0;
					ble_dt1 = 11 + (rnd%4);
					ble_dt2 = 5 + ((rnd*17)%5);
					dbg_val = ble_dt1;
					NRF_RNG->TASKS_START;
				}
			}
			if(ms - last_sent_ms > dt2 && ble_send_cnt == 1)
			{
				send_adv_packet();
				ble_send_cnt = 2;
				last_sent_ms = ms;
			}
			if(ms - last_sent_ms > dt2 && ble_send_cnt == 2)
			{
				send_adv_packet();
				last_sent_ms = ms;
				ble_send_cnt = 3;
			}
		}
	}

}

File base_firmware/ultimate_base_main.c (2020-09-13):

/**
 */

#include <stdbool.h>
#include <stdint.h>
#include <math.h>
#include "nrf_delay.h"
#include "nrf_gpiote.h"
#include "boards.h"
#include "leds.h"
#include "fast_radio.h"
#include "timer_core.h"
#include "uart_interface.h"

//openocd -f interface/stlink-v2.cfg -f target/nrf52.cfg
//flash write_image erase _build/nrf52832_xxaa.hex

uint8_t pin_led1 = 26;
uint8_t pin_led2 = 27;
uint8_t pin_led3 = 28;

uint8_t pin_tx = 5;
uint8_t pin_rx = 4;


int data_packet_len = 64;
int sync_packet_len = 64;
uint8_t sync_packet[120];
uint8_t data_packet[120];

uint16_t cycle_id = 0;

uint8_t cycle_packet[260];

uint32_t last_uart_pos = 0;

uint32_t uart_buf_length;

int pack_length = 0;
int pack_state = 0;
int pack_begin = 0;

uint8_t ble_mode = 0;
uint8_t ble_timed = 0;

uint32_t last_pos_rep_time = 0;

void check_uart_packet()
{
	int pos = last_uart_pos;
	int upos = get_rx_position();
	uint32_t ms = millis();
	if(ms - last_pos_rep_time > 500)
	{
//		uprintf("%lu: pos %d upos %d\n", ms, pos, upos);
		last_pos_rep_time = ms;
	}
	if(pos == upos) return;
//	uprintf("%lu: pos %d upos %d\n", ms, pos, upos);
	last_uart_pos = upos;
	
	int unproc_length = 0;
	unproc_length = upos - pos;
	if(unproc_length < 0) unproc_length += uart_buf_length;
	uint8_t *ubuf = get_rx_buf();
	
//	uint8_t msg_start[16];
//	for(int x = 0; x < 16; x++)
//		msg_start[x] = ubuf[pos+x];
//	uart_send(msg_start, 16);
	
	for(uint8_t pp = pos; pp != upos; pp++)
	{
		if(pp >= uart_buf_length) pp = 0;
		if(pack_state == 0 && ubuf[pp] == 29)
		{
			pack_state = 1;
			continue;
		}
		if(pack_state == 1)
		{
			if(ubuf[pp] == 115) pack_state = 2;
			else pack_state = 0;
			continue;
		}
		if(pack_state == 2)
		{
			pack_length = ubuf[pp];
			if(pack_length >= uart_buf_length-2) //something is wrong or too long packet
			{
				pack_length = 0;
				pack_state = 0;
				continue;
			}
			pack_begin = pp+1;
			if(pack_begin >= uart_buf_length) pack_begin = 0;
			pack_state = 3;
			continue;
		}
		if(pack_state == 3)
		{
			int len = pp - pack_begin;
			if(len < 0) len += uart_buf_length;
			if(len >= pack_length)
			{
				int bg = pack_begin;
				for(int x = 0; x < pack_length; x++)
				{
					sync_packet[x] = ubuf[bg++];
					if(bg >= uart_buf_length) bg = 0;
				}
				int cmd_packet = 0;
				if(sync_packet[0] == 177 && sync_packet[1] == 103 && sync_packet[2] == 39)
				{
					cmd_packet = 1;
					fr_ble_mode(37);
					fr_listen();
					ble_mode = 1;
					ble_timed = 0;
				}
				if(sync_packet[0] == 177 && sync_packet[1] == 103 && (sync_packet[2] >= 40 && sync_packet[2] <= 42))
				{
					cmd_packet = 1;
					fr_disable();
					if(sync_packet[2] == 40) fr_ble_mode(37);
					if(sync_packet[2] == 41) fr_ble_mode(38);
					if(sync_packet[2] == 42) fr_ble_mode(39);
					fr_listen();
					ble_mode = 1;
					ble_timed = 0;
				}
				if(sync_packet[0] == 177 && sync_packet[1] == 104 && (sync_packet[2] >= 40 && sync_packet[2] <= 42))
				{
					cmd_packet = 1;
					fr_disable();
					if(sync_packet[2] == 40) fr_ble_mode(37);
					if(sync_packet[2] == 41) fr_ble_mode(38);
					if(sync_packet[2] == 42) fr_ble_mode(39);
					fr_listen();
					ble_mode = 1;
					ble_timed = 1;
				}
				if(sync_packet[0] == 103 && sync_packet[1] == 177 && sync_packet[2] == 39)
				{
					cmd_packet = 1;
					fr_init(data_packet_len);
					fr_listen();
					ble_mode = 0;
				}

				if(!cmd_packet)
				{
					fr_send_and_listen(sync_packet);
					leds_set_pwm(0, 255*((millis()%500)<250));
//					uprintf("pack sent %d %d\n", last_uart_pos, upos);
				}
				else
					uart_send(sync_packet, pack_length+2);
				pack_state = 0;
			}
		}
	}
	last_uart_pos = upos;
}

void fast_clock_start()
{
	NRF_CLOCK->EVENTS_HFCLKSTARTED = 0;
	NRF_CLOCK->TASKS_HFCLKSTART = 1;
	while (NRF_CLOCK->EVENTS_HFCLKSTARTED == 0) {}
}
void slow_clock_start()
{
	NRF_CLOCK->LFCLKSRC = 0;
	NRF_CLOCK->TASKS_LFCLKSTART = 1;
	while (NRF_CLOCK->EVENTS_LFCLKSTARTED == 0) {}
}
void fast_clock_stop()
{
	slow_clock_start();
	NRF_CLOCK->TASKS_HFCLKSTOP = 1;
}

int main(void)
{
	NRF_UICR->NFCPINS = 0;
	fast_clock_start();

	uart_buf_length = get_rx_buf_length();

	start_time();
	
	leds_init();

	leds_set_pwm(0, 255);
	leds_set_pwm(1, 255);
	for(int x = 0; x < 3; x++)
	{
		leds_set_pwm(2, 255);
		delay_ms(200);
		leds_set_pwm(2, 0);
		delay_ms(200);
	}
	
	leds_set_pwm(0, 220);
	leds_set_pwm(1, 0);
	leds_set_pwm(2, 200);
    // Configure LED-pins as outputs
	delay_ms(1000);

//	leds_set_pwm(1, 255);
//	leds_set_pwm(0, 255);

	fr_init(data_packet_len);
	fr_mode_tx_only();
	
	uint16_t sync_pack_id = 0;
	
//	uart_init(20, 19);
	uart_init(pin_tx, pin_rx);
	
//	uprintf("ultimate base running\n");
	for(int n = 0; n < 50; n++)
		cycle_packet[n] = 0;
//	cycle_packet[17] = 79;
//	cycle_packet[18] = 213;

	uint8_t sync_sent = 0;
	int data_count = 0;
	uint32_t last_rx_packet_time;
	uint32_t last_sync_time = 0;
	uint32_t last_sync_ms = 0;
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

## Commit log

2019-04-06 initial PCB design commit
    [uECG_v2.kicad_pcb, uECG_v2.sch]
2019-04-06 added rendered schematics and 3D view
2019-08-15 updated to PCB version 4
    [uECG_rev4.kicad_pcb, uECG_rev4.sch, uECG_v2.kicad_pcb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]
2019-08-17 Firmware for 4th PCB revision initial commit
2019-09-30 base unit PCB added
    [ultimate_base.kicad_pcb, ultimate_base.sch]
2020-02-06 major firmware update, fixed critical bug in BLE mode, improved communication protocol, also set of minor changes
    [bmi160.c, leds.c, main.c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]
2020-02-17 critical bug in timing fixed
    [leds.c, main.c]
2020-02-18 direct mode version corrected
    [main.c]
2020-02-18 added fix of received BPM and RR intervals from the device
2020-09-12 added bootloaders: USB bootloader for the base station and radio bootloader for uECG device, finally firmware update will be as simple as Arduino!
2020-09-12 uECG firware update for bootloader use: fixed multiple bugs, added temperature measurement, and built in a bootloader-compatible way. This firware version should be uploaded via bootloader instead of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
    [bmi160.c, main.c, mcp3911.c]
2020-09-12 bugfix: using interrupt after VTOR update
    [main.c]
2020-09-13 small bugfixes & recompiled binaries
    [ultimate_base_main.c]
2020-09-13 bugfix affecting nodejs interface compatibility, recompiled binaries
    [main.c]

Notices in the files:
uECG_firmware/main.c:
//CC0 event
